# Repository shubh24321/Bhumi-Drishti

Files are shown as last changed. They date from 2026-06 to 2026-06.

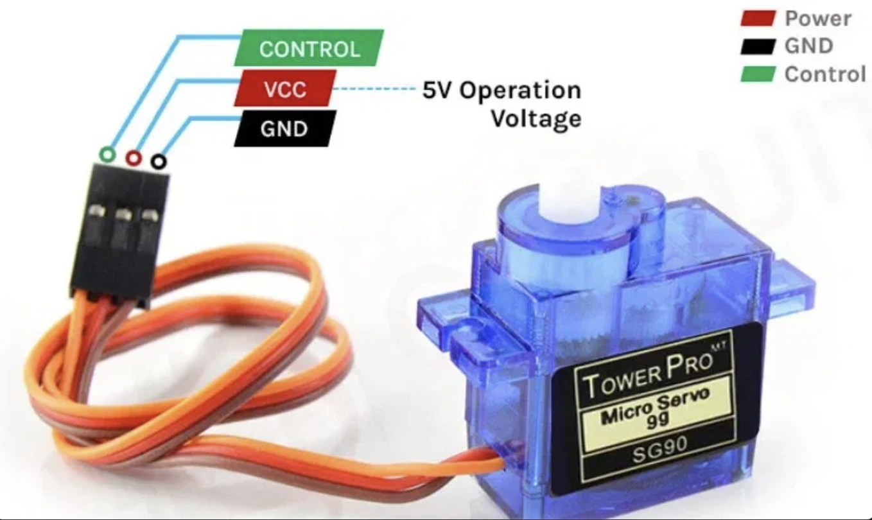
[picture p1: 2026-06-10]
hardware/sensor component/SG90.png

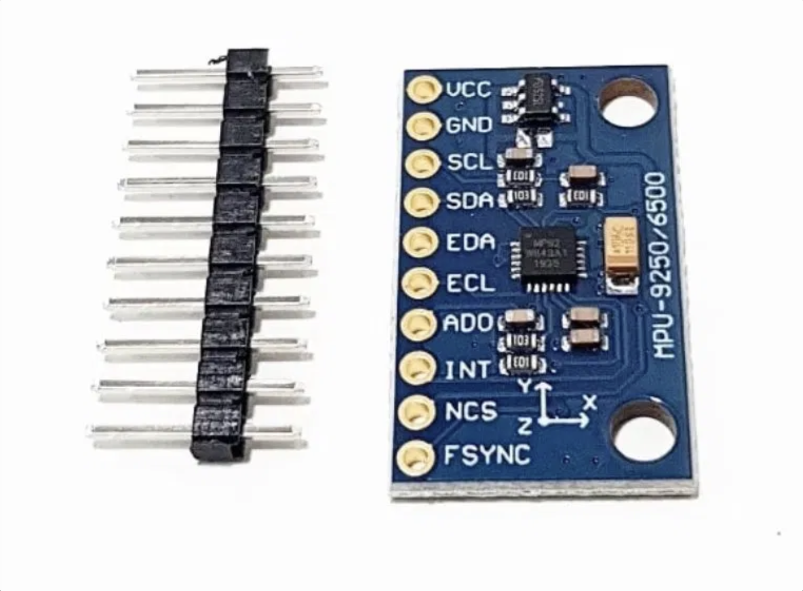
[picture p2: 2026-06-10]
hardware/sensor component/MPU6500.png

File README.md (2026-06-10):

# Bhumi Drishti 🛰️
### 1U CubeSat High-Altitude Balloon Mission

[]()
[]()
[]()
[]()

A student-built 1U CubeSat (100×100×113.5 mm) flown on a weather balloon
to the stratosphere. Sensors measure pressure, temperature, magnetic field,
and GPS coordinates throughout ascent and descent.

## Mission Overview

- **Platform:** 1U CubeSat form factor (100 × 100 × 113.5 mm)
- **Launch vehicle:** 600g weather balloon
- **Target altitude:** 20,000 – 40,000 m (stratosphere)
- **Flight computer:** Arduino Nano
- **Sensors:** BMP280 (pressure + temp) · HMC5883L (magnetometer) · Neo-6M (GPS)
- **Data storage:** SD card, CSV format
- **Recovery:** Parachute + GSM backup tracker

## Repository Structure
```
Bhumi-Drishti/
├── firmware/          # Arduino .ino source files
├── hardware/          # Wiring diagrams, PCB files
├── data/              # Sample CSV logs from tests
├── docs/              # Mission plan, test reports
└── analysis/          # Post-flight data scripts
```

## Current Status
- [x] Phase 1 — Team formed, workspace created
- [ ] Phase 2 — Sensor integration & demo build
- [ ] Phase 3 — Environmental testing
- [ ] Phase 4 — Launch preparation & DGCA approval
- [ ] Phase 5 — Launch & recovery

## Team
Built by a 4-person student team based in India.

## License
MIT — open science, open data.

## System Architecture
(docs/System Architecture/system architecture.png)

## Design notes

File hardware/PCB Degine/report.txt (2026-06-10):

Info: Processing symbol 'J1:'.
Info: Processing symbol 'J2:'.
Info: Processing symbol 'J3:'.
Info: Processing symbol 'J4:'.
Info: Processing symbol 'J5:'.
Info: Total warnings: 0, errors: 5.

Error: Cannot add J1 (no footprint assigned).
Error: Cannot add J2 (no footprint assigned).
Error: Cannot add J3 (no footprint assigned).
Error: Cannot add J4 (no footprint assigned).
Error: Cannot add J5 (no footprint assigned).

Info: Total warnings: 0, errors: 5.

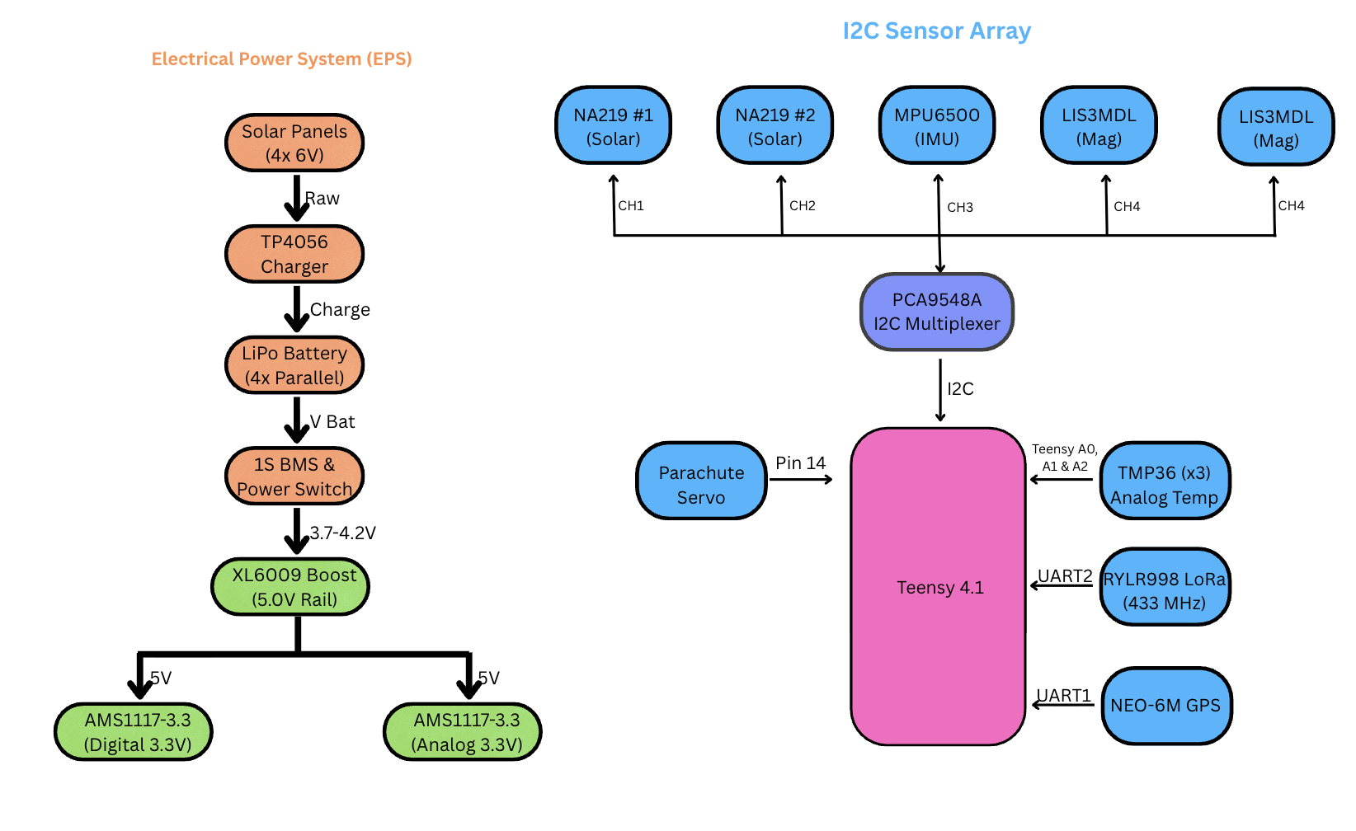
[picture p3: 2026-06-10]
docs/System Architecture/system architecture.png

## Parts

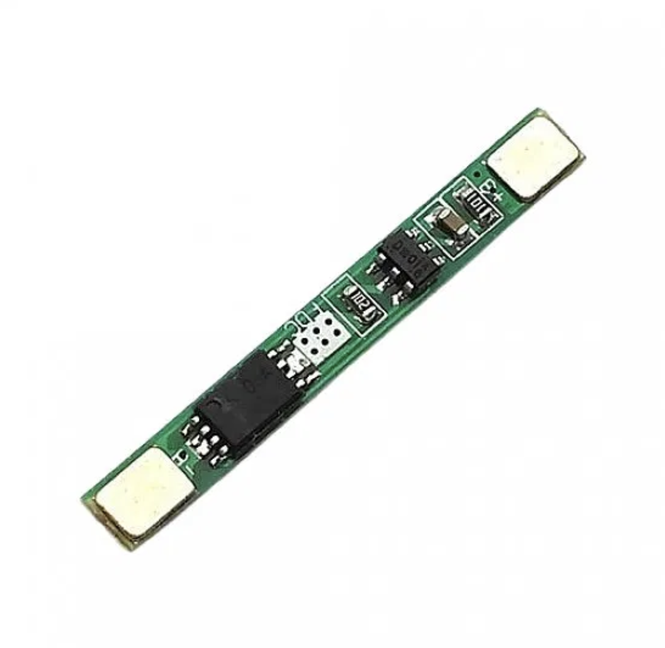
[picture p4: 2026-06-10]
hardware/sensor component/1S BMS.png

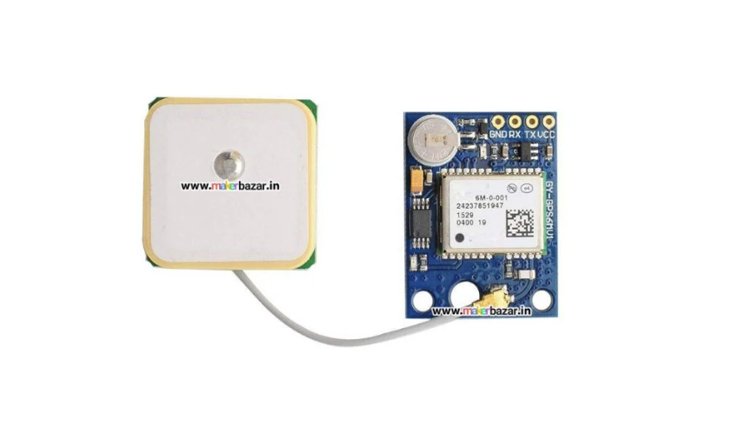
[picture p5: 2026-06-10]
hardware/sensor component/NE0-6M GPS.png

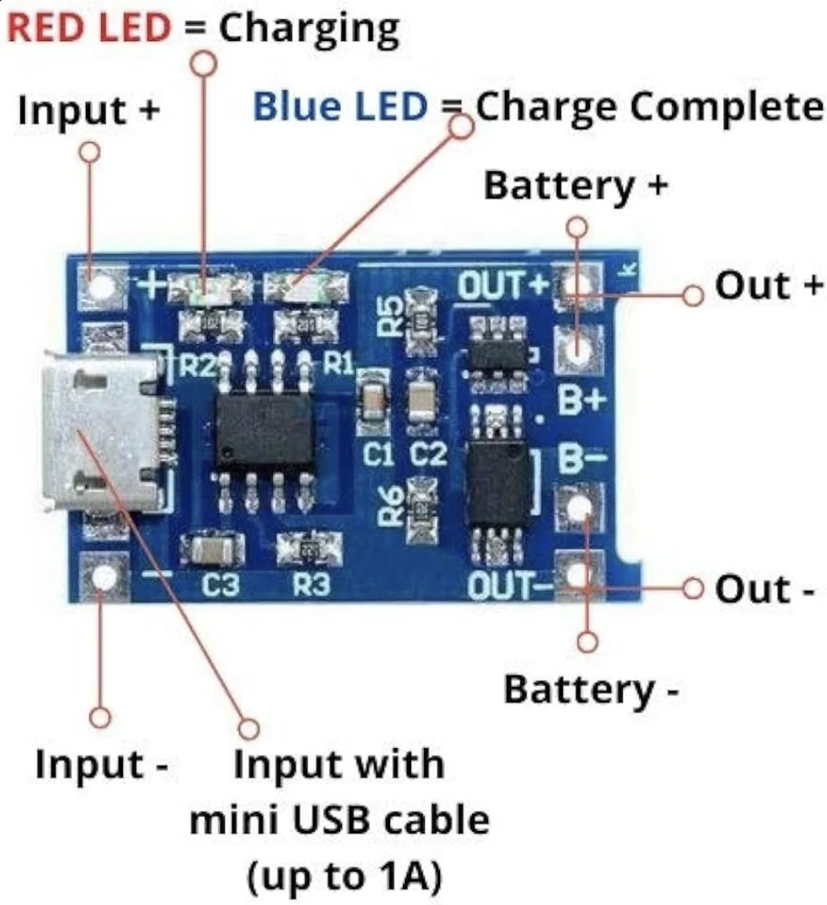
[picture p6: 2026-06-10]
hardware/sensor component/TP4056.png

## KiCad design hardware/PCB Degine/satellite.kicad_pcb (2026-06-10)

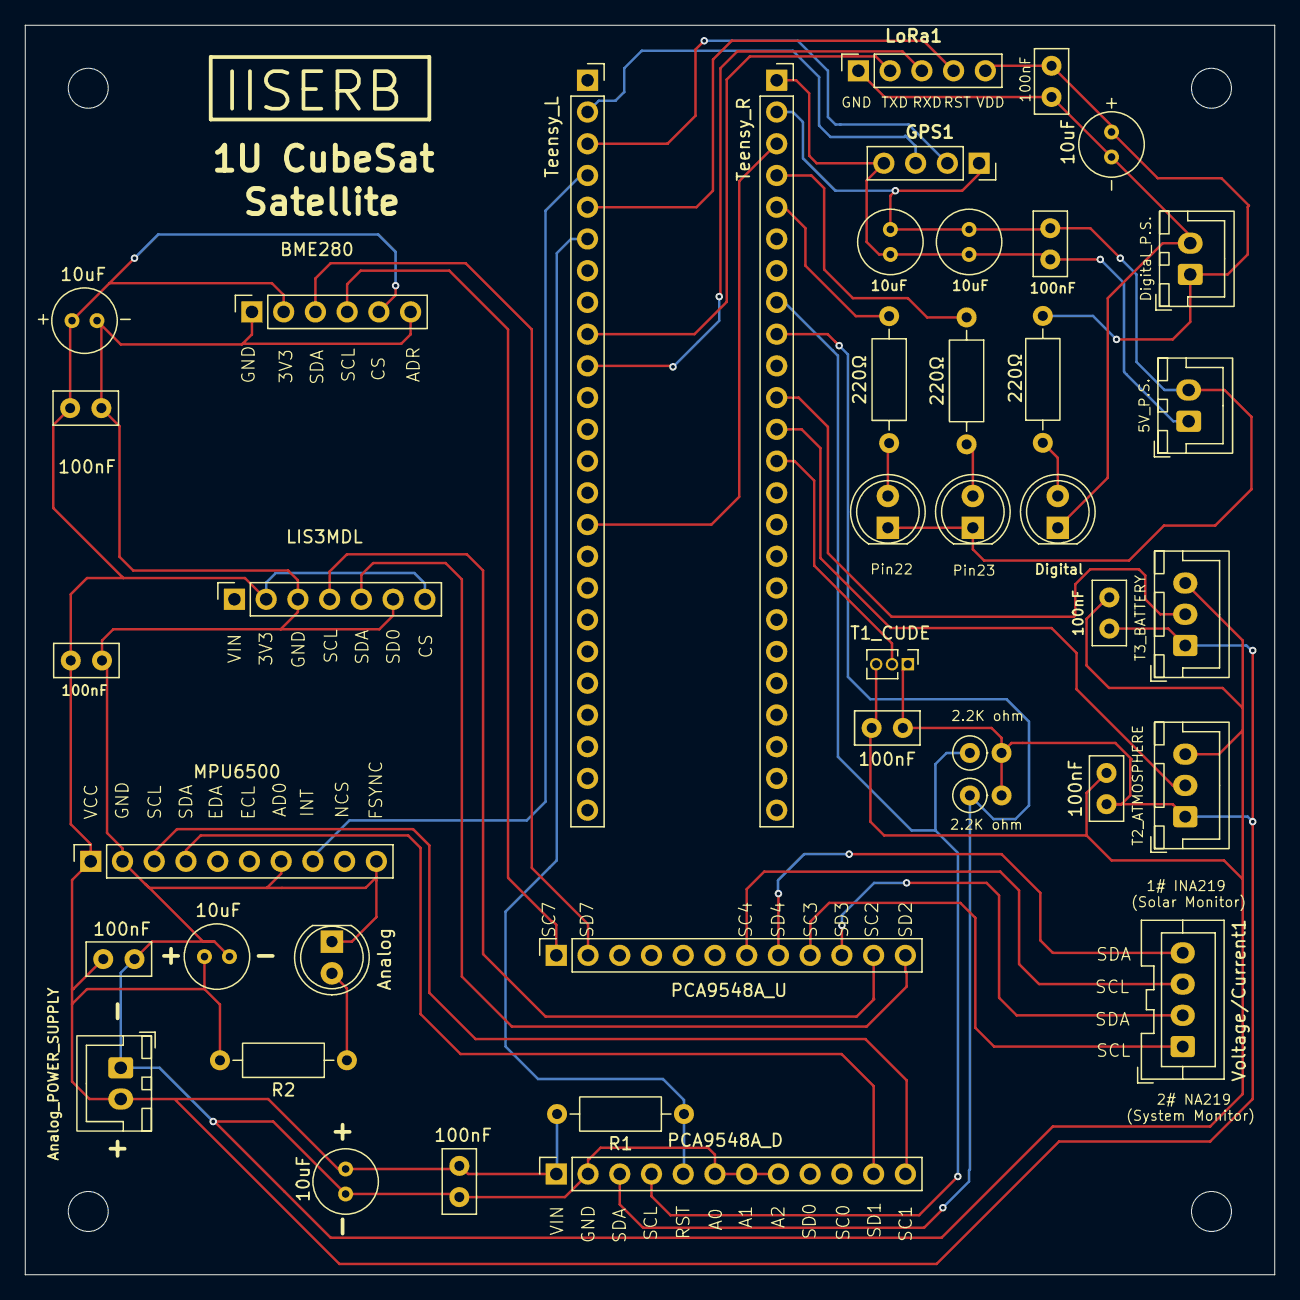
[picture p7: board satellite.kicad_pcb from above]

Board: 2 copper layers, 100.0 x 100.0 mm, 46 parts (0 on the bottom side), 35 nets.

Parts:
5V_P.S.: Conn_01x02_Socket; JST_XH_B2B-XH-A_1x02_P2.50mm_Vertical
10uF, 10uF#2, 10uF#3, 10uF#4, 10uF#5, 10uF#6: C; C_Radial_D5.0mm_H5.0mm_P2.00mm
100nF, 100nF#2, 100nF#3, 100nF#4, 100nF#5, 100nF#6, 100nF#7, 100nF#8, 100nF#9: C; C_Disc_D5.0mm_W2.5mm_P2.50mm
Analog: LED; LED_D5.0mm
Analog_POWER_SUPPLY: Conn_01x02_Socket; JST_XH_B2B-XH-A_1x02_P2.50mm_Vertical
BME280: Conn_01x06_Socket; PinSocket_1x06_P2.54mm_Vertical
Digital: LED; LED_D5.0mm
Digital_P.S.: Conn_01x02_Socket; JST_XH_B2B-XH-A_1x02_P2.50mm_Vertical
GPS1: Conn_01x04_Socket; PinSocket_1x04_P2.54mm_Vertical
H1, H2, H3, H4: MountingHole; MountingHole_3.2mm_M3
LIS3MDL: Conn_01x07_Socket; PinSocket_1x07_P2.54mm_Vertical
LoRa1: Conn_01x05_Socket; PinSocket_1x05_P2.54mm_Vertical
MPU6500: Conn_01x10_Socket; PinSocket_1x10_P2.54mm_Vertical
PCA9548A_D, PCA9548A_U: Conn_01x12_Socket; PinSocket_1x12_P2.54mm_Vertical
Pin22, Pin23: LED; LED_D5.0mm
R1: 10kΩ; R_Axial_DIN0207_L6.3mm_D2.5mm_P10.16mm_Horizontal
R2, R3, R4, R5: 220Ω; R_Axial_DIN0207_L6.3mm_D2.5mm_P10.16mm_Horizontal
R6, R7: 2.2K; R_Axial_DIN0207_L6.3mm_D2.5mm_P2.54mm_Vertical
T1_CUDE: Conn_01x03_Socket; PinHeader_1x03_P1.27mm_Vertical
T2_ATMOSPHERE, T3_BATTERY: Conn_01x03_Socket; JST_XH_B3B-XH-A_1x03_P2.50mm_Vertical
Teensy_L: TEENSY 4.1; PinSocket_1x24_P2.54mm_Vertical
Teensy_R: Conn_01x24_Socket; PinSocket_1x24_P2.54mm_Vertical
Voltage/Current1: Conn_01x04_Pin; JST_XA_B04B-XASK-1_1x04_P2.50mm_Vertical

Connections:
/0: GPS1.3, Teensy_L.2
/1: GPS1.2, Teensy_L.3
/2: MPU6500.8, Teensy_L.4
/3: LoRa1.4, Teensy_L.5
/3.3V_A: 10uF#2.2, 10uF#3.2, 10uF#5.2, 100nF.2, 100nF#2.1, 100nF#3.2, 100nF#4.1, 100nF#6.2, 100nF#7.1, 100nF#9.1, Analog_POWER_SUPPLY.2, BME280.2, BME280.5, LIS3MDL.2, LIS3MDL.7, MPU6500.1, PCA9548A_D.1, R1.2, R2.2, R6.2, R7.2, T1_CUDE.1, T2_ATMOSPHERE.1, T3_BATTERY.1
/3.3V_T: Teensy_L.15, Teensy_R.3
/4: PCA9548A_D.5, R1.1, Teensy_L.6
/5V_Buck: 5V_P.S..1, 10uF.2, 10uF#6.2, 100nF#5.2, GPS1.4, Teensy_R.1
/7: LoRa1.2, Teensy_L.9
/8: LoRa1.3, Teensy_L.10
/14: T1_CUDE.2, Teensy_R.13
/15: T2_ATMOSPHERE.2, Teensy_R.12
/16: T3_BATTERY.2, Teensy_R.11
/18: PCA9548A_D.3, R7.1, Teensy_R.9
/19: PCA9548A_D.4, R6.1, Teensy_R.8
/22: R4.1, Teensy_R.5
/23: R5.1, Teensy_R.4
/A0: 10uF#2.1, 10uF#3.1, 10uF#5.1, 100nF.1, 100nF#2.2, 100nF#3.1, 100nF#4.2, 100nF#6.1, 100nF#7.2, 100nF#9.2, Analog.1 (K), Analog_POWER_SUPPLY.1, BME280.1, BME280.6, LIS3MDL.3, LIS3MDL.6, MPU6500.2, MPU6500.7, MPU6500.10, PCA9548A_D.2, PCA9548A_D.6, PCA9548A_D.7, PCA9548A_D.8, T1_CUDE.3, T2_ATMOSPHERE.3, T3_BATTERY.3
/GND_BUCK: 5V_P.S..2, 10uF.1, 10uF#6.1, 100nF#5.1, GPS1.1, Pin22.1 (K), Pin23.1 (K), Teensy_R.2
/GND_Digital: 10uF#4.1, 100nF#8.1, Digital.1 (K), Digital_P.S..2, LoRa1.1
/SC1: MPU6500.3, PCA9548A_D.12
/SC2: LIS3MDL.4, PCA9548A_U.11
/SC3: PCA9548A_U.9, Voltage/Current1.1
/SC4: PCA9548A_U.7, Voltage/Current1.3
/SC7: BME280.4, PCA9548A_U.1
/SD1: MPU6500.4, PCA9548A_D.11
/SD2: LIS3MDL.5, PCA9548A_U.12
/SD3: PCA9548A_U.10, Voltage/Current1.2
/SD4: PCA9548A_U.8, Voltage/Current1.4
/SD7: BME280.3, PCA9548A_U.2
/VCC_Digital: 10uF#4.2, 100nF#8.2, Digital_P.S..1, LoRa1.5, R3.2
unnamed: Analog.2 (A), R2.1
unnamed: Digital.2 (A), R3.1
unnamed: Pin22.2 (A), R4.2
unnamed: Pin23.2 (A), R5.2

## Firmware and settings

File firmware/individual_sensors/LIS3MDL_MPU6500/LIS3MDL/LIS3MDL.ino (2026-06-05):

#include <Wire.h>
#include <math.h>

#define MUX_ADDR 0x70
#define MPU_ADDR 0x68
#define MAG_ADDR 0x1E
#define RST_PIN  4

void select(uint8_t ch) {
  Wire.beginTransmission(MUX_ADDR);
  Wire.write(1 << ch);
  Wire.endTransmission();
  delay(2); 
}

void writeReg(uint8_t dev, uint8_t reg, uint8_t val) {
  Wire.beginTransmission(dev);
  Wire.write(reg);
  Wire.write(val);
  Wire.endTransmission();
}

void setup() {
  Serial.begin(115200);
  pinMode(RST_PIN, OUTPUT);
  digitalWrite(RST_PIN, HIGH);
  Wire.begin();
  Wire.setClock(400000);
  
  select(1); writeReg(MPU_ADDR, 0x6B, 0x00); // Wake MPU
  select(2); writeReg(MAG_ADDR, 0x60, 0x8C); // Init MAG (100Hz)
  Serial.println("--- CubeSat Sensors Online ---");
}

void loop() {
  // --- MPU6500 Data ---
  select(1);
  Wire.beginTransmission(MPU_ADDR);
  Wire.write(0x3B);
  if (Wire.endTransmission() == 0 && Wire.requestFrom(MPU_ADDR, 6) == 6) {
    float ax = (int16_t)(Wire.read() << 8 | Wire.read()) / 16384.0;
    float ay = (int16_t)(Wire.read() << 8 | Wire.read()) / 16384.0;
    float az = (int16_t)(Wire.read() << 8 | Wire.read()) / 16384.0;
    Serial.printf("IMU Coordinate (g) – %.2f, %.2f, %.2f\n", ax, ay, az);
  }

  // --- LIS2MDL Data ---
  select(2);
  Wire.beginTransmission(MAG_ADDR);
  Wire.write(0x68);
  if (Wire.endTransmission() == 0 && Wire.requestFrom(MAG_ADDR, 6) == 6) {
    float mx = (int16_t)(Wire.read() | (Wire.read() << 8)) * 0.0015;
    float my = (int16_t)(Wire.read() | (Wire.read() << 8)) * 0.0015;
    float mz = (int16_t)(Wire.read() | (Wire.read() << 8)) * 0.0015;
    float bTotal = sqrt(mx*mx + my*my + mz*mz);
    
    Serial.printf("MAG Coordinate (G) – %.3f, %.3f, %.3f\n", mx, my, mz);
    Serial.printf("Total Magnetic Field – %.4f Gauss\n", bTotal);
  }

  Serial.println("----------------------------------------");
  delay(500); 
}

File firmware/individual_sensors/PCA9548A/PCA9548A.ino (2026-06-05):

#include <Wire.h>

// --- Configuration ---
#define MUX_ADDR 0x70      // Address with A0, A1, A2 to GND
#define RESET_PIN 4        // RST Pin with 10k pull-up to 3.3V
#define CHECK_INTERVAL 5000 

unsigned long lastCheck = 0;

void setup() {
  // Teensy 4.1 Serial is very fast, no baud rate required but 115200 is standard
  Serial.begin(115200);
  
  // wait for Serial Monitor
  while (!Serial && millis() < 3000);

  Serial.println("\n--- PCA9548A Hardware Test (Pull-Up Verified) ---");

  // 1. Initialize the Reset Pin
  // The 10k resistor holds this HIGH. We set it to OUTPUT to control it.
  pinMode(RESET_PIN, OUTPUT);
  digitalWrite(RESET_PIN, HIGH); 
  
  // 2. Start I2C on Pins 18 (SDA) and 19 (SCL)
  Wire.begin();
  
  // Optional: Increase I2C speed to 400kHz to test pull-up strength
  // Stronger pull-ups (2.2k) handle 400kHz better than internal ones.
  Wire.setClock(400000); 

  Serial.println("System Ready. Checking connection every 5s...");
}

void loop() {
  unsigned long now = millis();

  if (now - lastCheck >= CHECK_INTERVAL) {
    lastCheck = now;

    Serial.print("[Time: ");
    Serial.print(now / 1000);
    Serial.print("s] Scanning for Mux... ");

    // Perform an I2C discovery "ping"
    Wire.beginTransmission(MUX_ADDR);
    byte error = Wire.endTransmission();

    if (error == 0) {
      Serial.println("SUCCESS: PCA9548A is ONLINE at 0x70");
      Serial.println("-> Pull-up resistors are working correctly.");
    } 
    else if (error == 4) {
      Serial.println("HARDWARE ERROR 4: Bus Error.");
      Serial.println("-> Check if 2.2k resistors are correctly tied to 3.3V.");
    } 
    else {
      Serial.print("FAILED: Error Code ");
      Serial.println(error);
      Serial.println("-> Check A0/A1/A2 and Power connections.");
    }
    
    Serial.println("------------------------------------------------");
  }
}
